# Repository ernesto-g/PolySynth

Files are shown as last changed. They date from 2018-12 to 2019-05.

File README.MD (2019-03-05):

# 7 voices Poly Synth

Supported features:
  - 7 voices polyphony
  - Analog VCF
  - Sync in
  - Sync out
  - MIDI in
  - MIDI out
  - USB MIDI in  
  - Pedal in
  - Audio in

## Block diagram

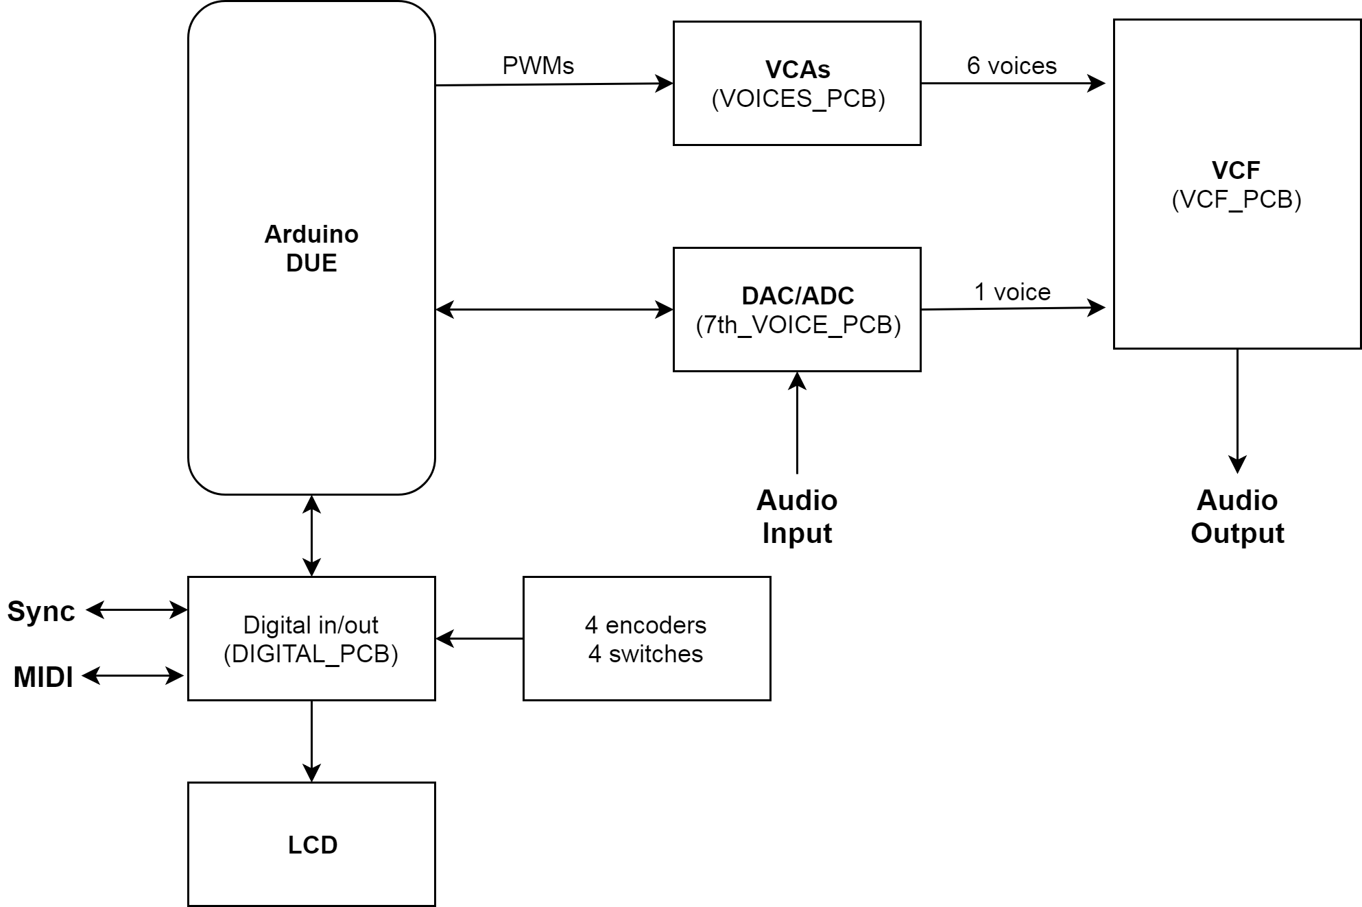
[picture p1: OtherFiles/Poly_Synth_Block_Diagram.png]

  
### This project contains:
  - Arduino Due Firmware
  - PCBs
  - Schematics 
  - Pictures   
  - Front panel blueprints

## License
  
7 voices Poly Synth
Copyright (C) <2019>  Ernesto Gigliotti <ernestogigliotti@gmail.com>
	
This program is free software: you can redistribute it and/or modify
it under the terms of the GNU General Public License as published by
the Free Software Foundation, either version 3 of the License, or
(at your option) any later version.

This program is distributed in the hope that it will be useful,
but WITHOUT ANY WARRANTY; without even the implied warranty of
MERCHANTABILITY or FITNESS FOR A PARTICULAR PURPOSE.  See the
GNU General Public License for more details.

You should have received a copy of the GNU General Public License
along with this program.  If not, see <https://www.gnu.org/licenses/>.

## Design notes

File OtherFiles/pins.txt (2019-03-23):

0: TX0 debug
1: TX1 debug
2: ADSR_VOICE0 (PWM)
3: ADSR_VOICE1 (PWM)
4: ADSR_VOICE2 (PWM)
5: ADSR_VOICE3 (PWM)

6: OUT_VOICE_4 (PWM) 
7: OUT_VOICE_5 (PWM)
8: PWM FAST FREE
9: PWM FAST FREE

10: ADSR_VOICE4 (PWM)
11: ADSR_VOICE5 (PWM)
12: ADSR_FILTER (PWM)
13: LFO_OUT (PWM)

14: TX3 FREE
15: RX3 FREE
16: TX2 MIDI OUT
17: RX2 MIDI IN
18: TX1 FREE
19: RX1 FREE
20: I2C_SDA_MEM
21: I2C_SCL_MEM

22: SW_BACK
23: FREE
24: SW_ENTER
25: FREE
26: SW_QL
27: FREE
28: SW_PK
29: FREE
30: SW_OJ
31: FREE
32: SW_MI

33: ENCODER_D_PIN_1
34: OUT_VOICE_0 (PWM)
35: ENCODER_D_PIN_2
36: OUT_VOICE_1 (PWM) 
37: ENCODER_C_PIN_1
38: OUT_VOICE_2 (PWM) 
39: ENCODER_C_PIN_2 
40: OUT_VOICE_3 (PWM) 
41: ENCODER_B_PIN_1
42: SYNC_IN
43: ENCODER_B_PIN_2
44: SUSTAIN_PEDAL_IN
45: ENCODER_A_PIN_1
46: SYNC_OUT 
47: ENCODER_A_PIN_2
48: SW_SHIFT
49: LCD_CS
50: FREE
51: LCD_DC
52: SD_CS
53: LCD_RES

AN0: AUDIO_IN_1 
AN1: AUDIO_IN_2 
AN2: FREE
AN3: FREE   
AN4: FREE
AN5: FREE
AN6: FREE 
AN7: FREE
AN8: FREE 
AN9: FREE
AN10: FREE
AN11: FREE

DAC0: AUDIO_OUT
DAC1: FREE

SPI_MOSI: LCD_MOSI
SPI_CLK: LCD_CLK

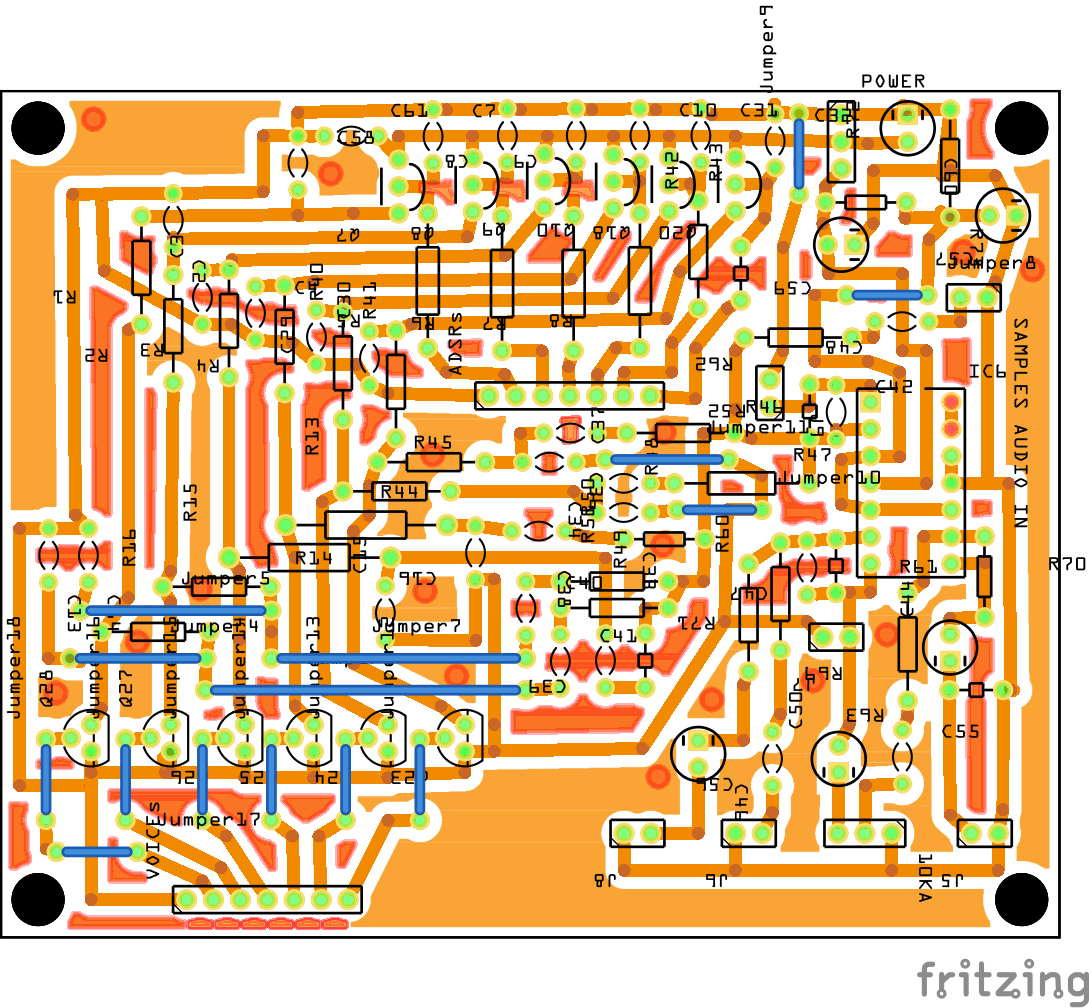
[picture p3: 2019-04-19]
PCB/VOICES_PCB/VOICES_pcb.png

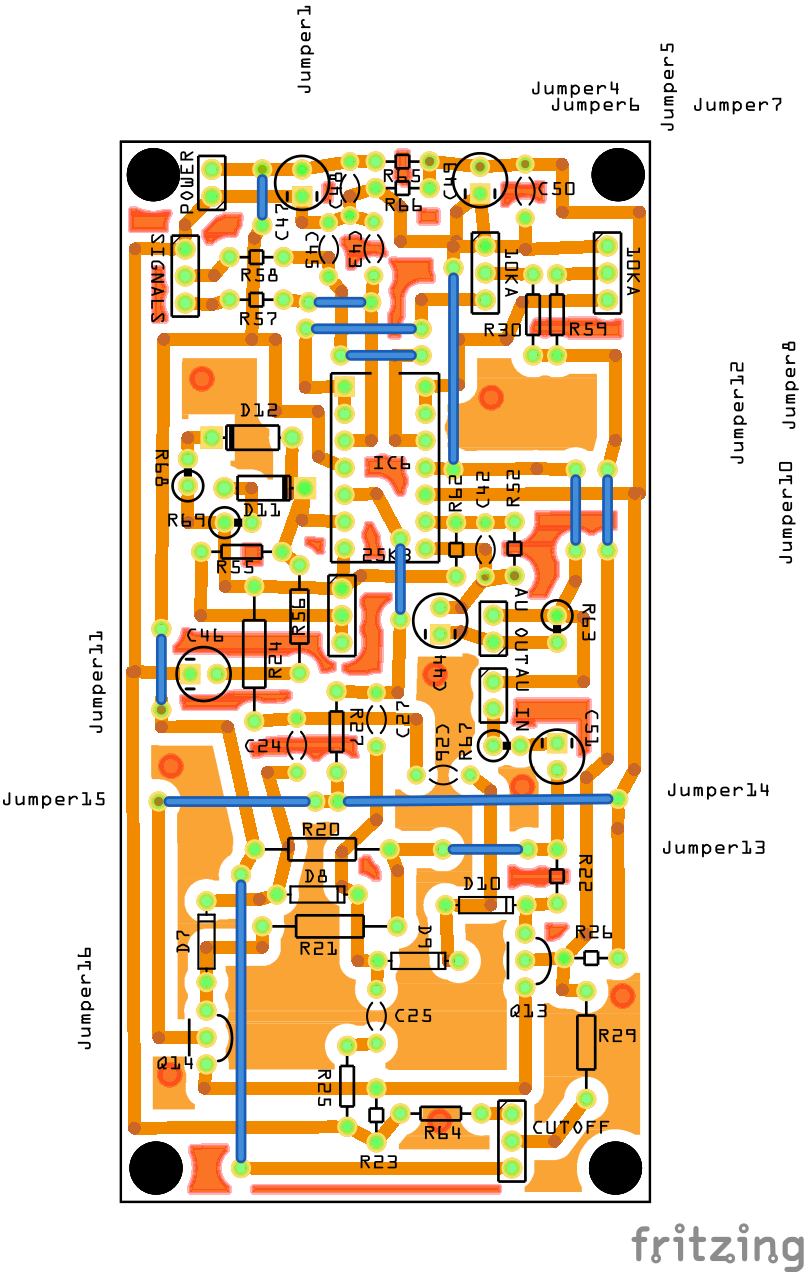
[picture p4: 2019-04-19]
PCB/VCF_PCB/VCF_pcb.png

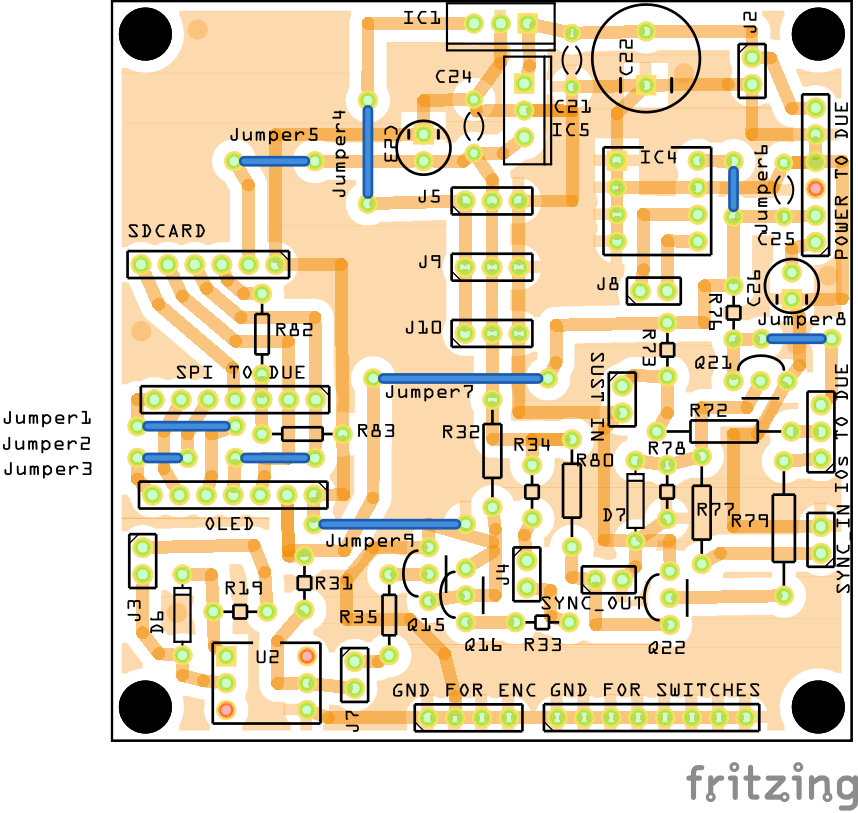
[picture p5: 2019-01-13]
PCB/DIGITAL_PCB/DIGITAL_pcb.png

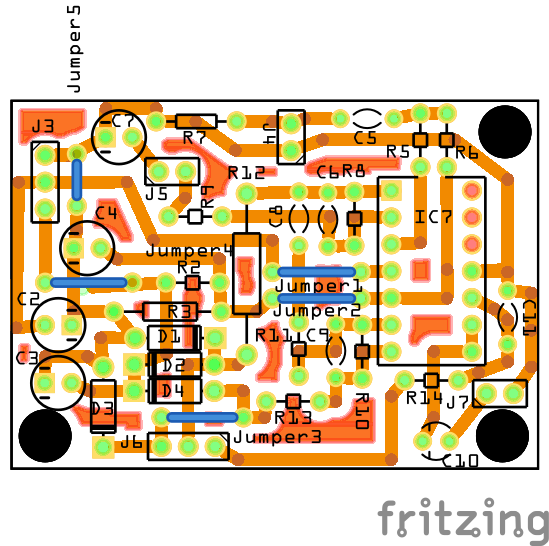
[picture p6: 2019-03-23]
PCB/7th_VOICE_PCB/7th_VOICE_pcb.png

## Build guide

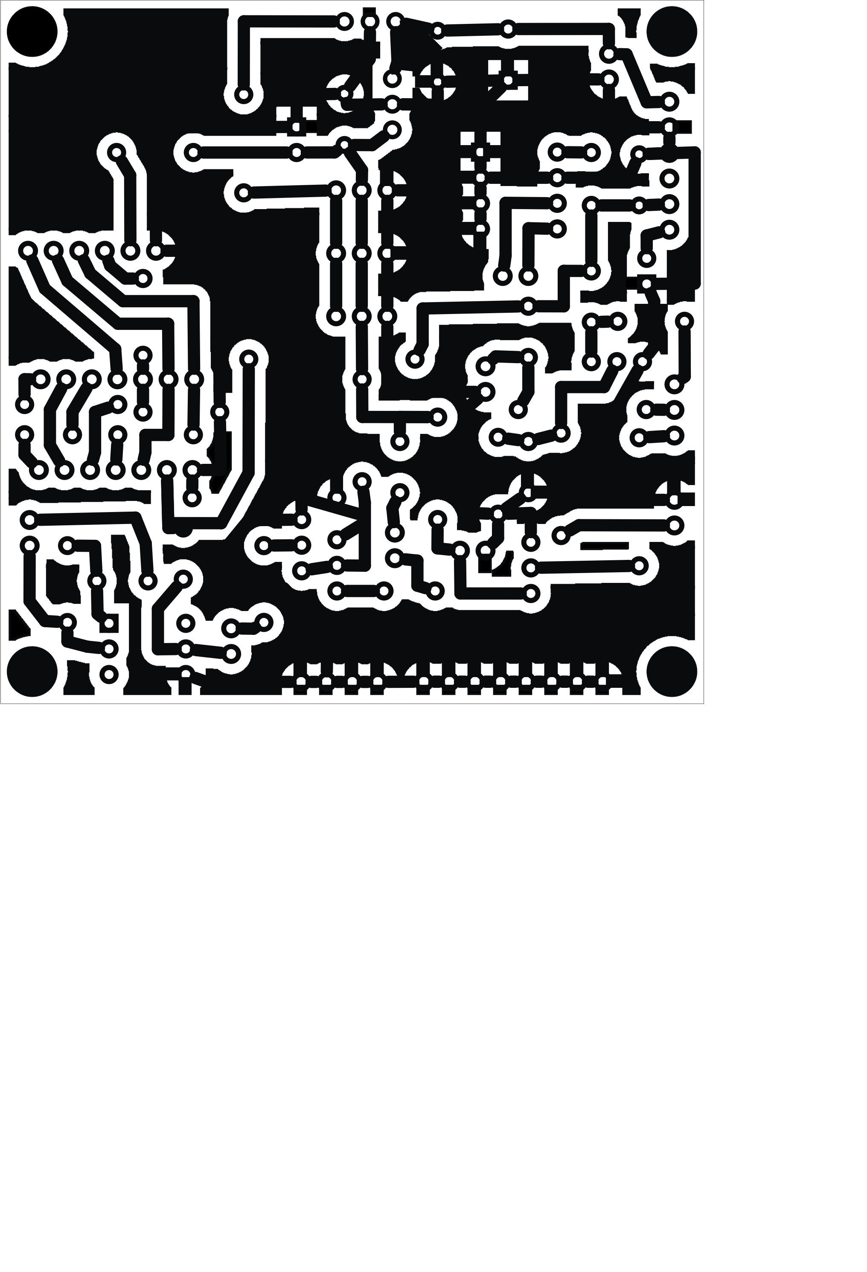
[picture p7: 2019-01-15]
PCB/DIGITAL_PCB/DIGITAL_PCB_TO_PRINT.png

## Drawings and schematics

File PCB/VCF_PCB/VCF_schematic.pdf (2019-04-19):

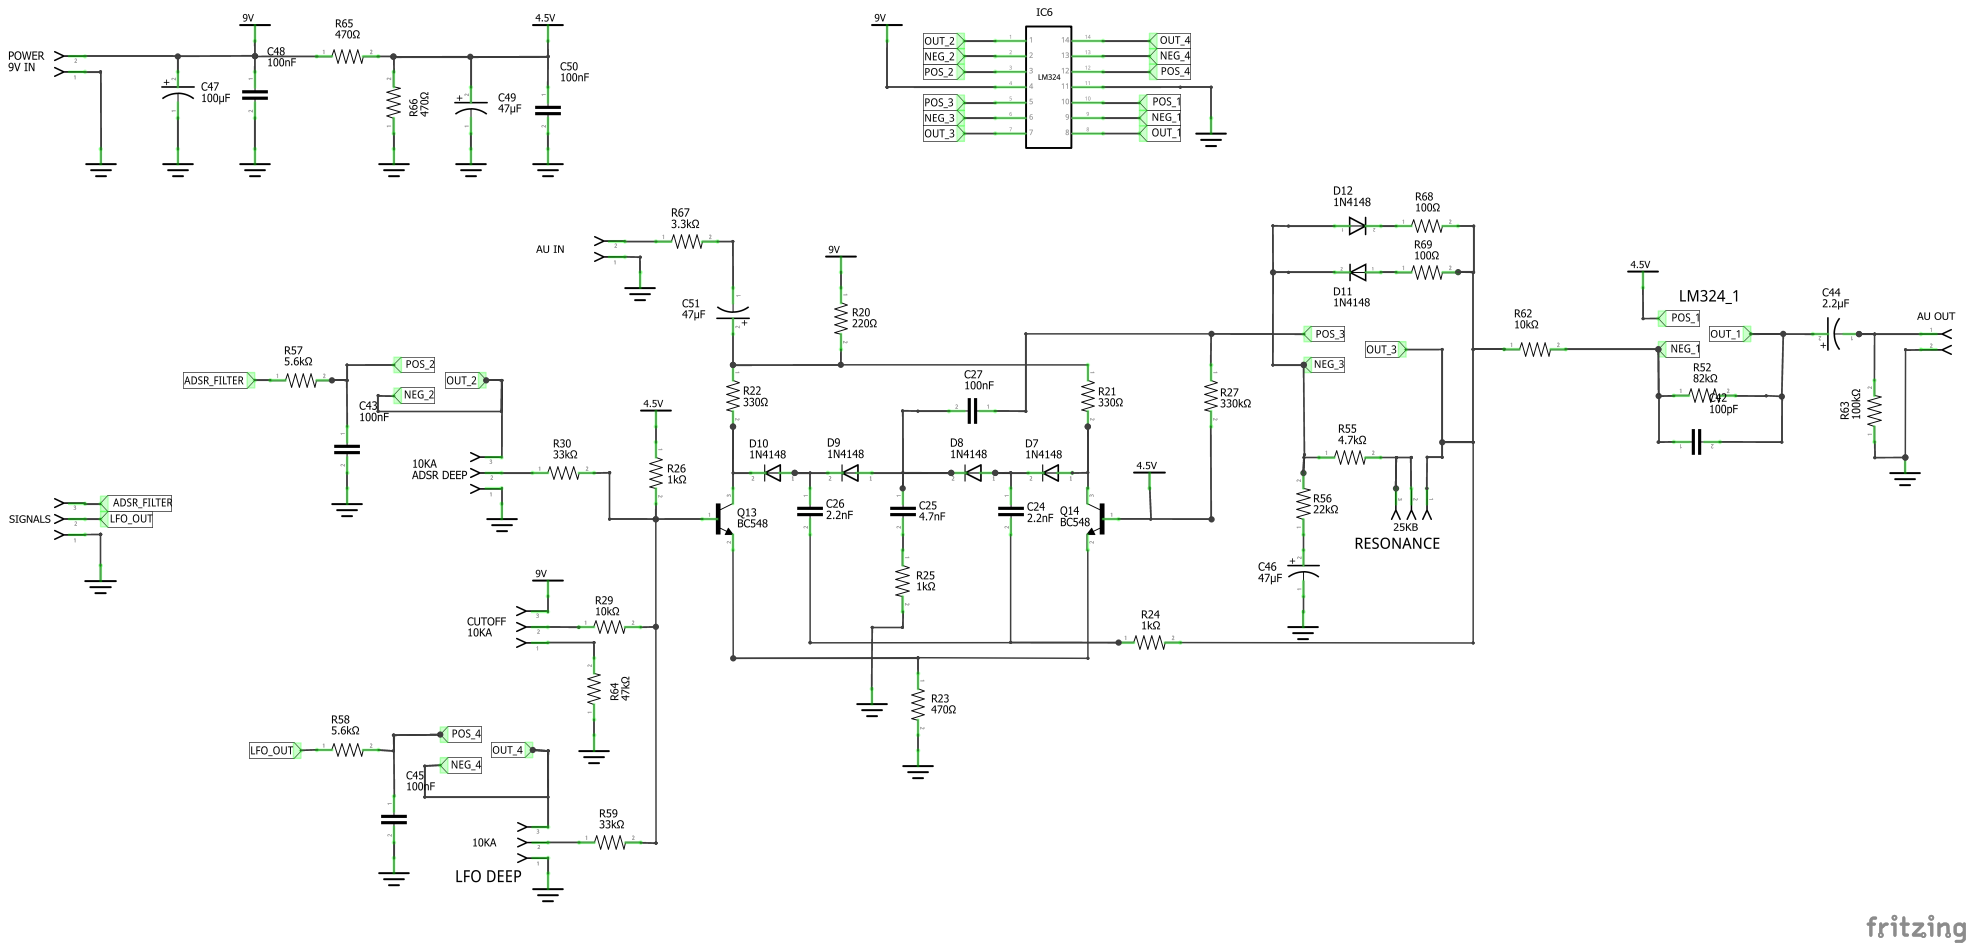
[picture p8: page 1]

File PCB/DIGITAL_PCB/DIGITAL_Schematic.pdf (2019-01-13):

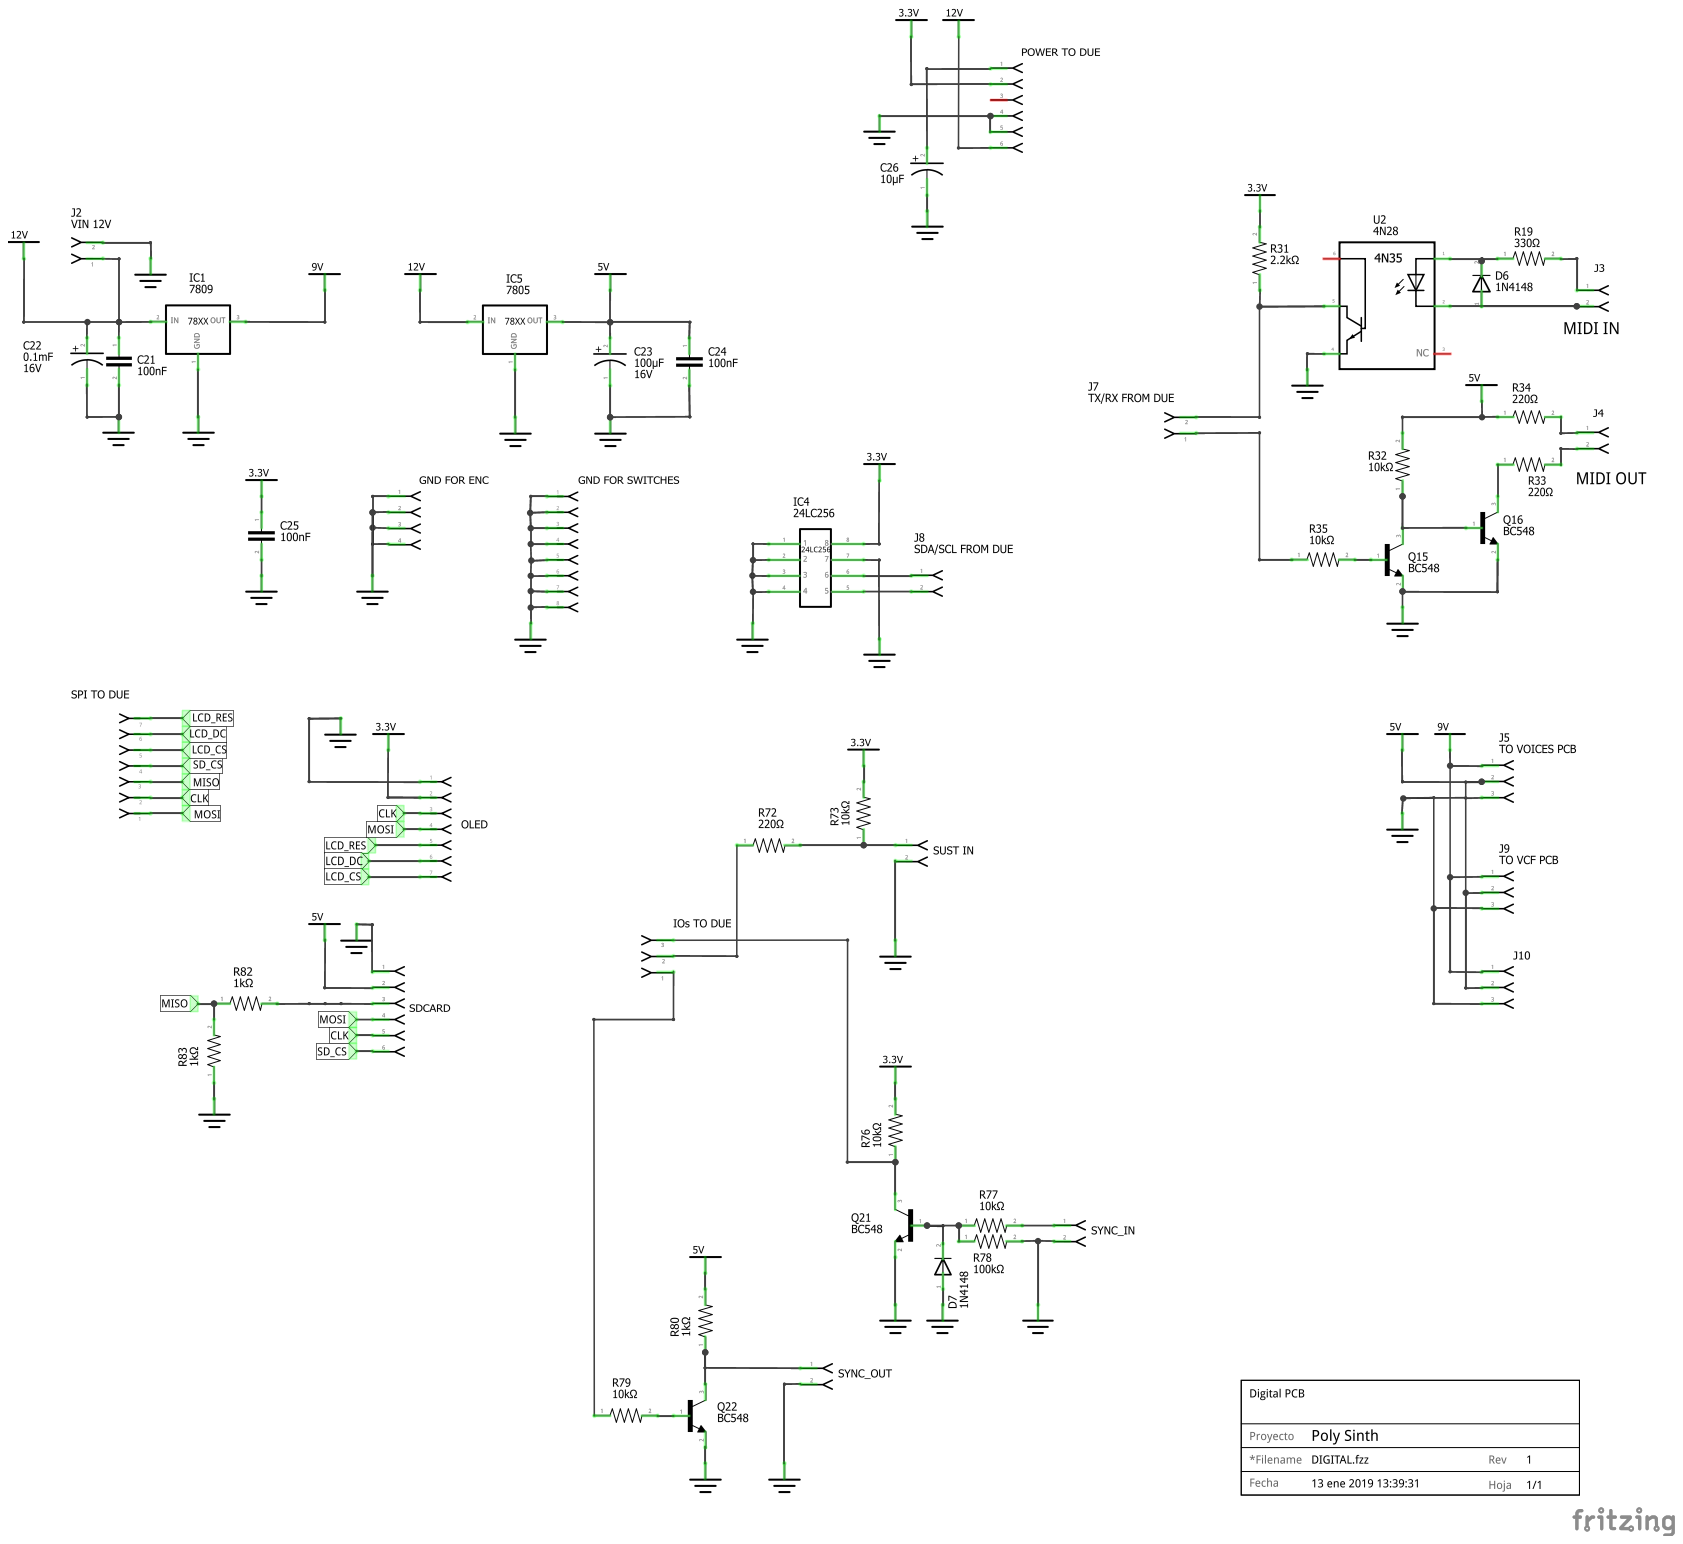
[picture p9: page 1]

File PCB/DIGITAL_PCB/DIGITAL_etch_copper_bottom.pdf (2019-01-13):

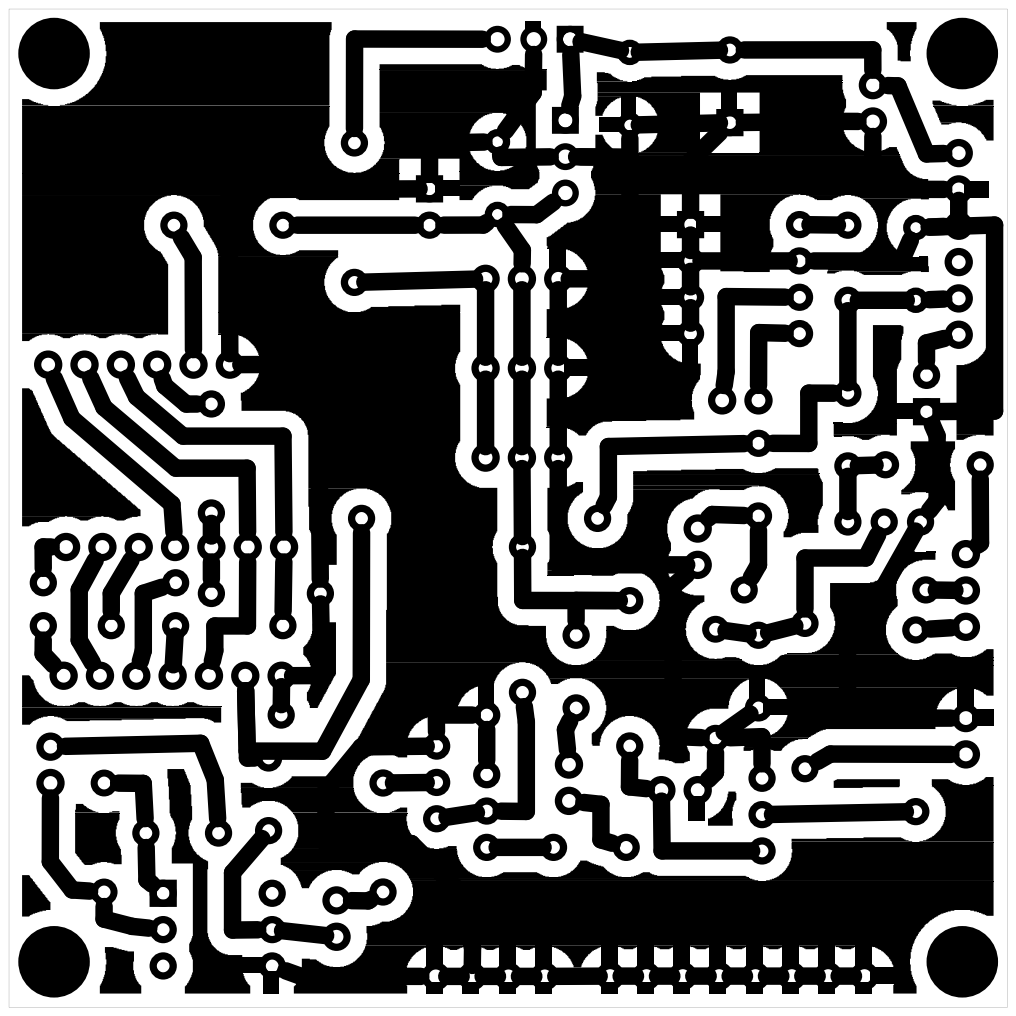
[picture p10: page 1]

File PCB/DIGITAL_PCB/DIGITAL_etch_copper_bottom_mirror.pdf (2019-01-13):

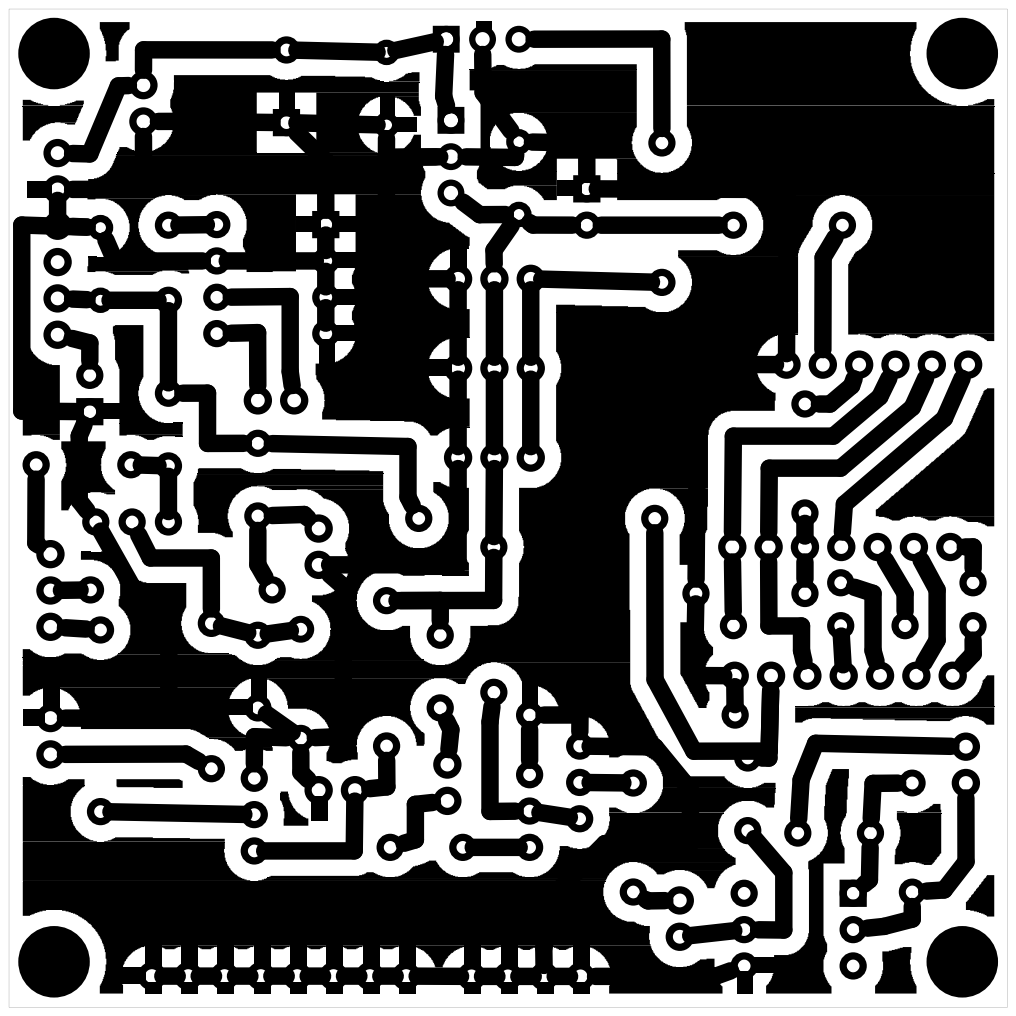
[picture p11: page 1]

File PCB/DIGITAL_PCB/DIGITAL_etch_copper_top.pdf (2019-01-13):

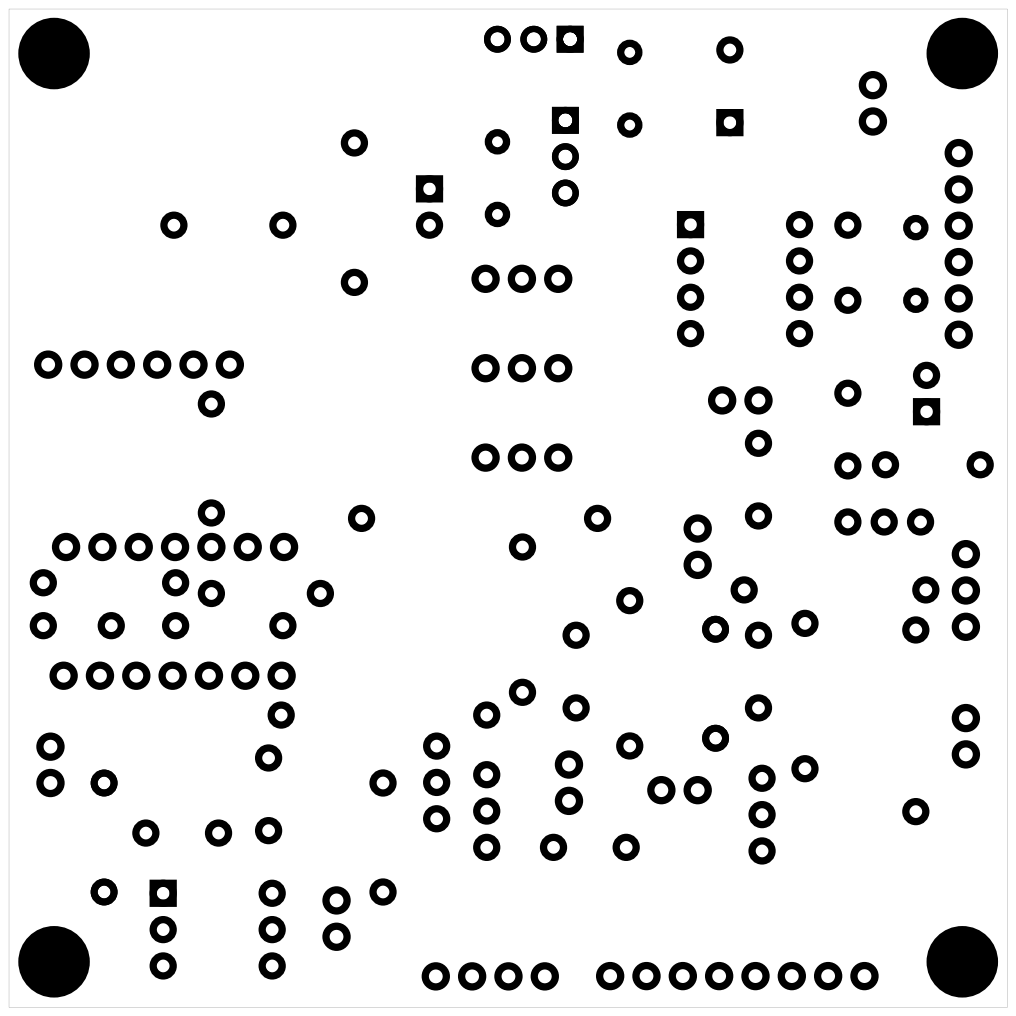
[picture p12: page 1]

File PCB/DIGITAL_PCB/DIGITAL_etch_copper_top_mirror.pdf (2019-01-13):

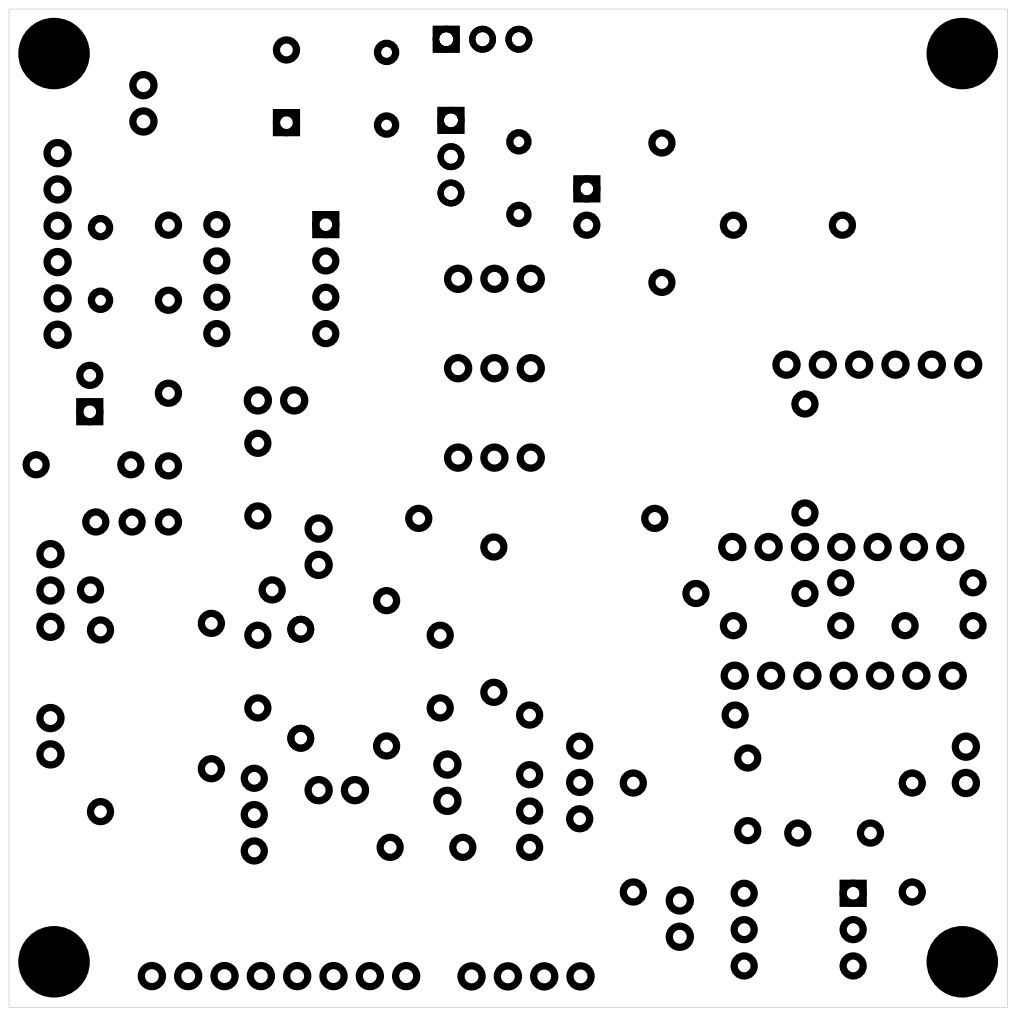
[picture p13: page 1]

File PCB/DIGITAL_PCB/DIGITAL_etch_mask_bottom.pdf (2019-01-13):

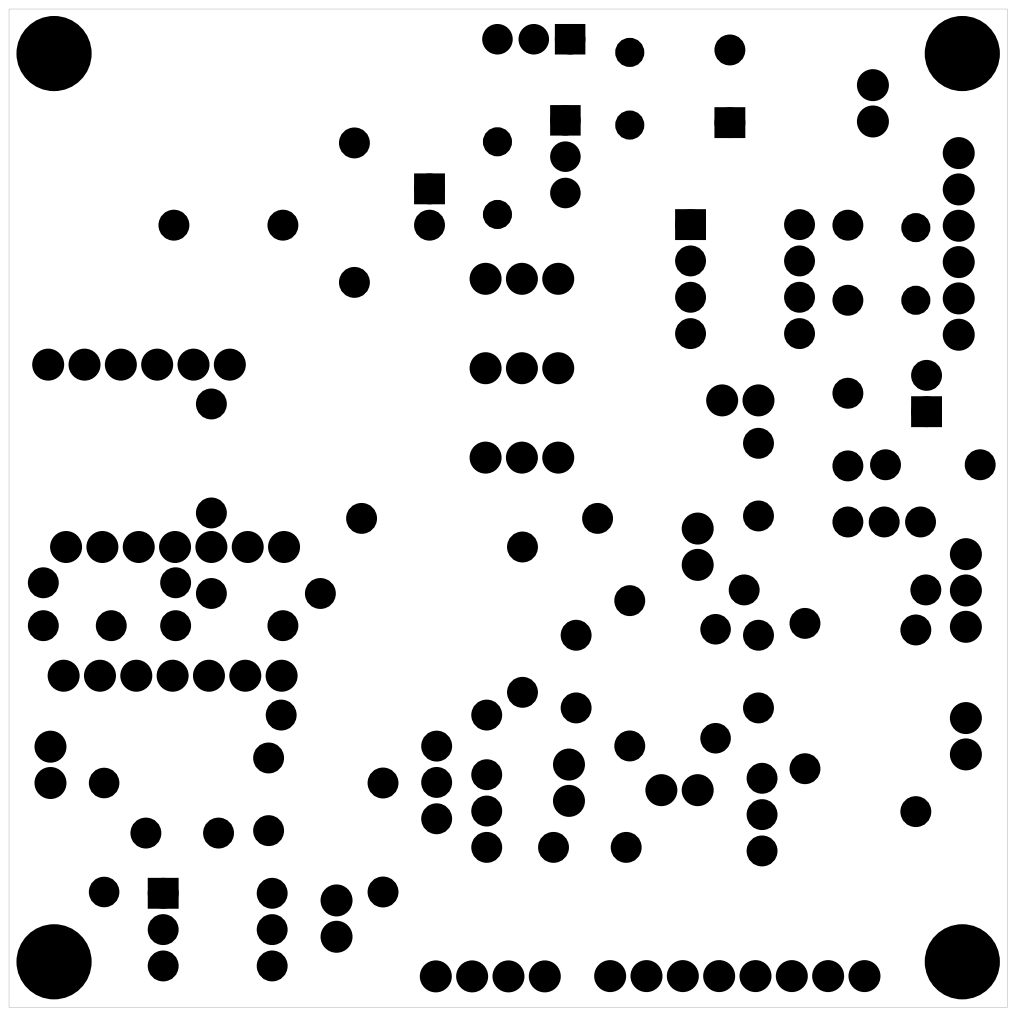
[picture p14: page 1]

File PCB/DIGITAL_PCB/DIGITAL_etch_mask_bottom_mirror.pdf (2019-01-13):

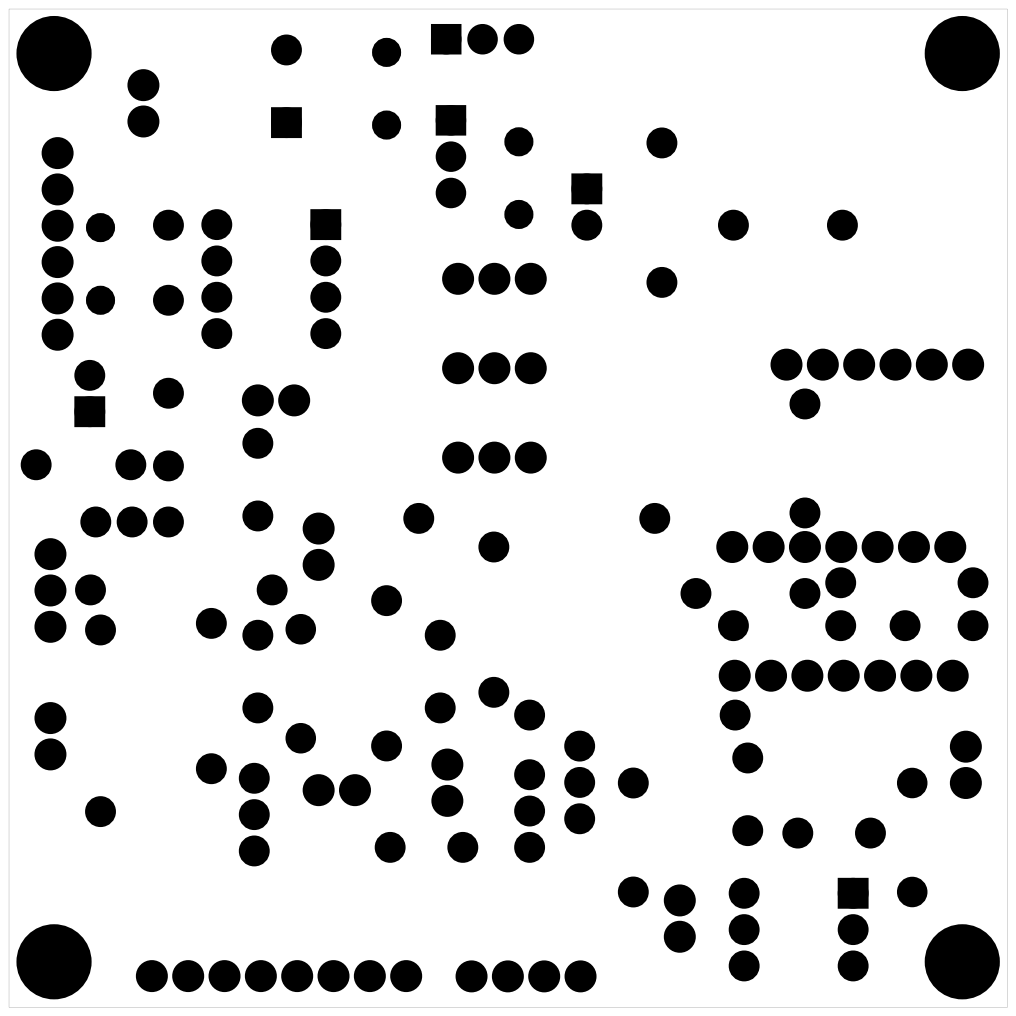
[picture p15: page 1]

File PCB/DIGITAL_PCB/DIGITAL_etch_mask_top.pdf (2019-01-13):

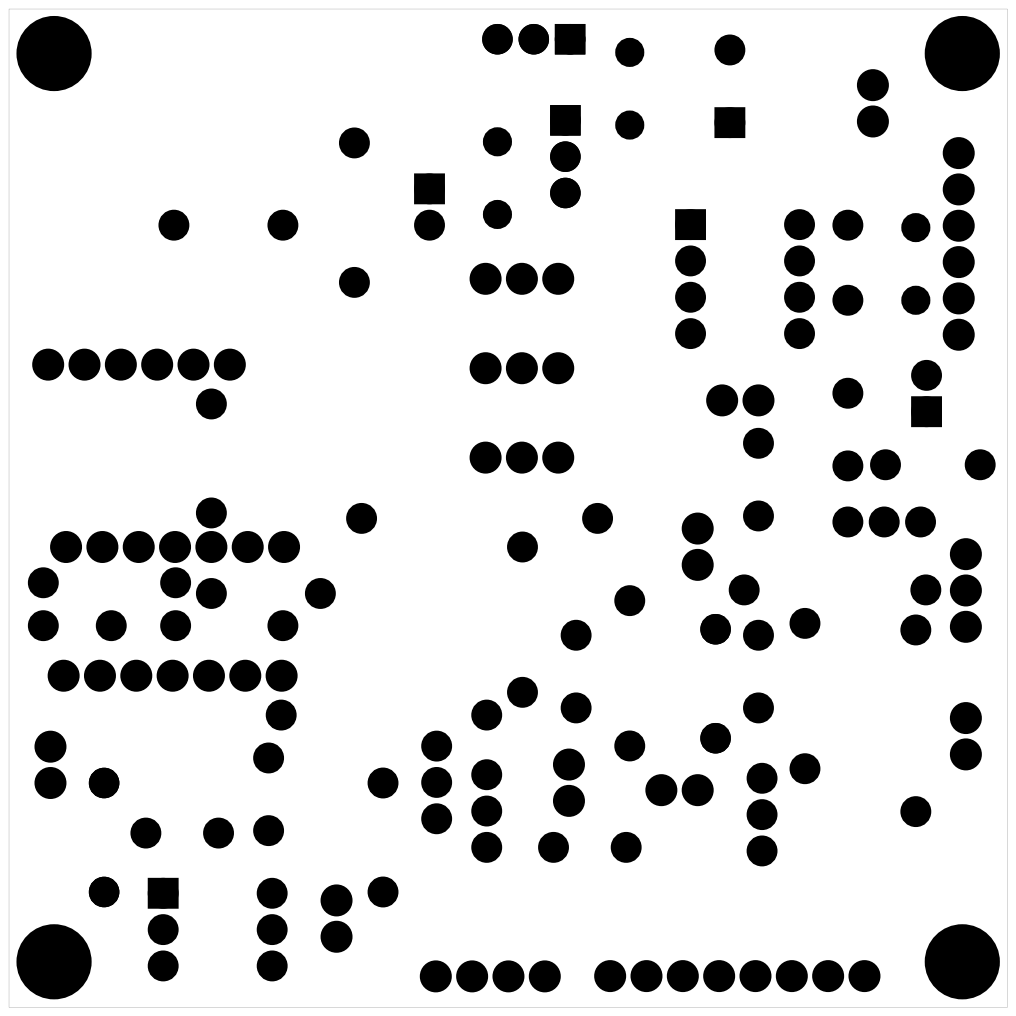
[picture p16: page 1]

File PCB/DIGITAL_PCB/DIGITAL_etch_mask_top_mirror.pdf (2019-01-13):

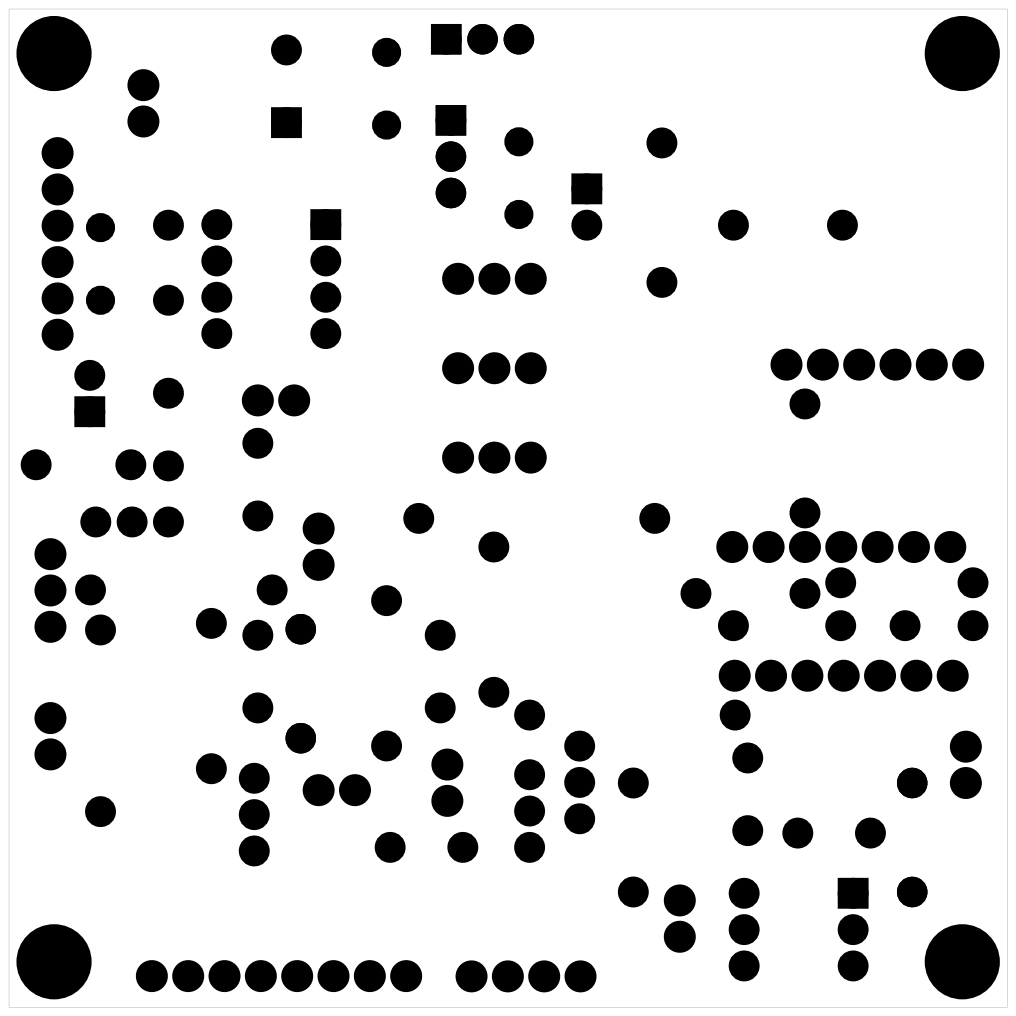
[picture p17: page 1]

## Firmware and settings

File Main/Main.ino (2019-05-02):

#include <Arduino.h>
#include "DueTimer.h"

#include <SPI.h>
#include <Wire.h>
#include "MenuManager.h"
#include "PwmManager.h"
#include "Dco.h"
#include "AdsrManager.h"
#include "MIDIReception.h"
#include "MIDIManager.h"
#include "FrontPanel.h"
#include "Memory.h"
#include "SequencerManager.h"

/**
 * COMPILATION NOTES
 * Edit ~\AppData\Local\Arduino15\packages\arduino\hardware\sam\1.6.11\platform.txt and change flags from -Os to -O3 
 */

#define PIN_SD_CS   52



void systick(void)
{
     frontp_tick1Ms();
     seq_sysTick();
}
  
void setup() {  
    Serial.begin(9600);

    // CS for SDcard disabled
    pinMode(PIN_SD_CS, OUTPUT);
    digitalWrite(PIN_SD_CS, HIGH); 
    //_______________________

    pwmm_init();
    dco_init();

    mem_init();

    midi_init();
    midircv_init();
    frontp_init();
    seq_init();

    dco_setWaveForm(0);

    Timer1.attachInterrupt(systick).setFrequency(1000).start(); // freq update: 1Khz 

    menu_init();


}


void loop() {

 
  while(1)
  {
      midircv_stateMachine();

      frontp_loop();

      seq_loop();

      menu_loop();

      if(adsr_areAllIdle())
      {
          // turn off LFO
          dco_lfoOff();
      }
    
  }
}

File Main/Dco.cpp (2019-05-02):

#include "pwm_lib.h"
#include "PwmManager.h"
#include "DueTimer.h"
#include "Dco.h"
#include "AdsrManager.h"
using namespace arduino_due::pwm_lib;



// ********************************************** PWM Management ************************************************************
pwm<pwm_pin::PWML0_PC2> pwm_pin34;
pwm<pwm_pin::PWML1_PC4> pwm_pin36;
pwm<pwm_pin::PWML2_PC6> pwm_pin38;
pwm<pwm_pin::PWML3_PC8> pwm_pin40;

pwm<pwm_pin::PWML4_PC21> pwm_pin9;
pwm<pwm_pin::PWML5_PC22> pwm_pin8;
pwm<pwm_pin::PWML6_PC23> pwm_pin7;
pwm<pwm_pin::PWML7_PC24> pwm_pin6;

typedef struct {
    Tc *pTC;        // TC0, TC1, or TC2
    byte channel;   // 0-2
    byte output;    // 0 = A, 1 = B
}  tTimerInfo;

tTimerInfo timerLookup [] =
{
  {NULL,0,0}, // 0
  {NULL,0,0},
  {TC0,0,0},  // pin 2 = TIOA0
  {TC2,1,0},  // pin 3 = TIOA7
  {TC2,0,1},  // pin 4 = TIOB6
  {TC2,0,0},  // pin 5 = TIOA6
  {NULL,0,0},
  {NULL,0,0},
  {NULL,0,0},
  {NULL,0,0},
  {TC2,1,1},  // pin 10 = TIOB7
  {TC2,2,0},  // pin 11 = TIOA8
  {TC2,2,1},  // pin 12 = TIOB8
  {TC0,0,1}   // pin 13 = TIOB0
};

static uint32_t setupTimerPwm (byte pin, uint32_t frequency, unsigned dutyCycle);
static inline void pwmm_setValuePwmFast(unsigned char index,unsigned int value);
static uint32_t setupTimerPwmInitTc (byte pin);
//___________________________________________________________________________________________________________________________

// ******************************************** Wave forms ******************************************************************
#include "WaveTables.c"

// ********************************************** DCO Management ************************************************************
#define VOICES_LEN    6
#define MIDI_C1_NOTE  24
#define SAMPLING_FREQ 64000

struct S_ddsInfo
{
  unsigned char delta; // 1:octave C1. 2: octave C2. 4: octave C3. 8: octave C4 ....
  const volatile short unsigned int* table; // table pointer to specific note and waveform
  unsigned int tableLen;  
  unsigned char enabled;
  unsigned int counterMax;
  unsigned int counter;
};
typedef struct S_ddsInfo DDSInfo;

static void dcoUpdateForWaveSamples(void);
static void dcoUpdateForADSRs(void);
inline static void dcoUpdateSamples(void);
static int searchFreeVoice(void);
static float getFreqByNote(int note);

static void lfoUpdate(void);
static void lfoModulations(void);

static volatile unsigned int synthWaveform;
static volatile DDSInfo ddsInfo[VOICES_LEN];
static volatile signed int voices[VOICES_LEN];
static volatile unsigned int n[VOICES_LEN];

// LFO
#define LFO_WAVE_TYPE_SINE        4
#define LFO_WAVE_TYPE_TRIANGLE    3
#define LFO_WAVE_TYPE_EXP         2
#define LFO_WAVE_TYPE_SQUARE      1
#define LFO_WAVE_TYPE_RANDOM      0

#define INC_RANDOM_COUNTER()  {randomCounter++; if(randomCounter>=(RANDOM_TABLE_SIZE-1)) randomCounter=0;}

static volatile unsigned short randomCounter=0;
static volatile int lfoCounter=0;
static volatile int lfoFreqMultiplier=30;
static volatile int lfoSampleAndHoldNewSampleFlag=0;
static volatile int lfoSampleAndHoldValue;
static volatile int lfoOn=0;
static volatile int lfoWaitZero=1;
static volatile int lfoWaveType=LFO_WAVE_TYPE_SINE;
static volatile int lfoSignedValue;
static volatile int lfoAmplitudeAmt=25;


//___________________________________________________________________________________________________________________________

void dco_init(void)
{
    int i;
    for(i=0;i<VOICES_LEN; i++)
    {
      voices[i]=0;
      n[i]=0;
      ddsInfo[i].enabled=0;
    }
    synthWaveform = 0;
    //_________ 

    adsr_init();
    
    Timer3.attachInterrupt(dcoUpdateForWaveSamples).setFrequency(SAMPLING_FREQ).start();
    Timer4.attachInterrupt(dcoUpdateForADSRs).setFrequency(14400).start(); // freq update: 14.4Khz 
}


void dco_setWaveForm(int wf)
{
    synthWaveform = wf;
}
int dco_getWaveForm(void)
{
    return synthWaveform;
}


int dco_setNote(int note, int vel)
{
    INC_RANDOM_COUNTER();
  
    if(note<MIDI_C1_NOTE)
        return -1;
    note = note-MIDI_C1_NOTE;
    
    int baseNote = note%12; // C:0 .... B:11
    int octave = note/12;

    //Serial.print("llego nota C3, busco voice libre");
    int indexFreeVoice = searchFreeVoice();
    if(indexFreeVoice>=0)
    {
        n[indexFreeVoice]=0;
        ddsInfo[indexFreeVoice].table=waveTablesInfo[synthWaveform].table[baseNote]; //table
        ddsInfo[indexFreeVoice].delta=(1<<octave); // octave
        ddsInfo[indexFreeVoice].tableLen = waveTablesInfo[synthWaveform].len[baseNote]; // table len
        ddsInfo[indexFreeVoice].enabled = 1;

        adsr_triggerEvent(indexFreeVoice, vel);

        dco_lfoOn();
    }
    return indexFreeVoice;
}
void dco_releaseVoice(int voice)
{
    adsr_gateOffEvent(voice);
}

void dco_disableVoice(int index)
{
    ddsInfo[index].enabled=0;
}

void dco_releaseAllVoices(void)
{
      int i;
    for(i=0;i<VOICES_LEN; i++)
      dco_releaseVoice(i);      
}


static void dcoUpdateForWaveSamples(void)
{
    // Generate waveform
    dcoUpdateSamples();

    // Set PWMs
    int i;
    for(i=0;i<VOICES_LEN; i++)
      pwmm_setValuePwmFast(i,(voices[i]>>4));
    //_________  

}

inline static void dcoUpdateSamples(void)
{
    int i;
    for(i=0;i<VOICES_LEN; i++)  // 4.45uS with 6 voices
    {
        
        if(ddsInfo[i].enabled==0)
        {
            voices[i] = PWM_FAST_MAX_VALUE/2;
            continue;
        } 

        n[i]+=ddsInfo[i].delta;
        
        if(n[i] >= ddsInfo[i].tableLen )
            n[i] = n[i]-ddsInfo[i].tableLen;

        voices[i] = ddsInfo[i].table[n[i]];
    } 
}


static int lfoDivider=0;
static void dcoUpdateForADSRs(void)
{
    adsr_stateMachineTick(); 

    lfoDivider++;
    if(lfoDivider>10)
    {
        lfoUpdate();
        lfoDivider=0;
    }

    INC_RANDOM_COUNTER();
}


static int searchFreeVoice(void)
{
    int adsrIndex = adsr_getFreeAdsr(VOICES_LEN);
    if(adsrIndex>=0)
    {
        return adsrIndex;
    }
    return -1;
}

static float getFreqByNote(int note)
{
    return NOTES_FREQ_TABLE[note];
}
   

// LFO management ************************************************************************************
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

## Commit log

2018-11-30 wave table and filter tests
2018-11-30 generic dds. filter commented. saw waveform test
2018-12-01 samples generation script using python and 1 period.
2018-12-05 samples tests
2018-12-08 slow pwms working
2018-12-08 adsr OK with voice disable/enable management
    [PWM_MOD.DSN]
2018-12-09 fix pwm tc b channel error
    [Dco.cpp, Main.ino]
2018-12-12 mem library. pcb first sh
    [Synth_Shield_PCB.fzz]
2018-12-17 schematic voices ok
    [Synth_Shield_PCB.fzz]
2018-12-21 schematic lfo to filter control
    [Synth_Shield_PCB.fzz]
2018-12-24 to do list for schematic
    [Synth_Shield_PCB.fzz]
2018-12-30 voices PCB finished
    [MAIN.fzz, Synth_Shield_PCB.fzz, VOICES.fzz]
2019-01-02 voices pcb completed
    [VOICES.fzz]
2019-01-02 PCB finished.
    [VOICES.fzz]
2019-01-09 fix slow pwm setup
    [Dco.cpp, Main.ino]
2019-01-11 digital pcb
    [DIGITAL.fzz]
2019-01-11 Digital pcb. schematic ok
    [DIGITAL.fzz, VCF_K.DSN]
2019-01-12 digital pcb almost finished
    [DIGITAL.fzz]
2019-01-13 digital pcb ok
    [DIGITAL.fzz]
2019-01-15 PCB to print
2019-02-06 files architecture restructured
    [PWM_MOD.DSN, VCF.fzz, VCF_K.DSN]
2019-03-05 7th voice pcb
    [7th_VOICE.fzz]
2019-03-05 readme added. block diagram
    [7th_VOICE.fzz, MAIN.fzz, Synth_Shield_PCB.fzz]
2019-03-23 7th voice pcb finished.
    [7th_VOICE.fzz]
2019-03-23 encoders and sws tests
2019-04-07 first menu and mini piano test. 4 samples loaded
2019-04-07 encoder fix
2019-04-13 fix encoders priority
2019-04-18 main sample synth screen
2019-04-19 vcf r values for cutoff. voices_pcb file was generated
    [VCF.fzz]
2019-04-22 lfo modulation ok. reload encoders for different items ok
2019-04-22 back button implemented
2019-05-12 out of voices fix. velocity feature for attack and sustain
    [AdsrManager.cpp, Memory.cpp]
